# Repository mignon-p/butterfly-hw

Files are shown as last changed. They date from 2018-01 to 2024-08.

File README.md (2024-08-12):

This repository contains the [KiCad][5] and [Gerber][6] files for a
PCB nightlight shaped like a butterfly.

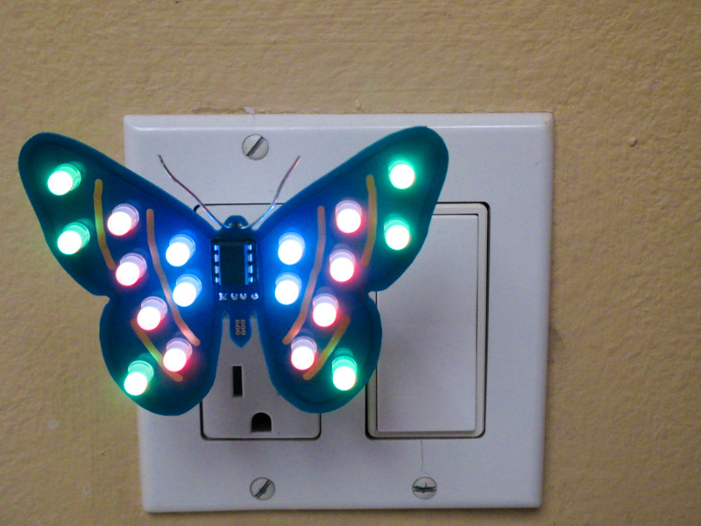
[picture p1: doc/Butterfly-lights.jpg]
photo of nightlight


The nightlight contains 18 "NeoPixel" (WS-2812) LEDs, controlled by an
ATtiny85 microcontroller.  (The firmware for the microcontroller is in
[a separate repository][7].)

There is a tiny potentiometer on the back, which can be used to
control the brightness.  (This functionality is handled in software,
so it could potentially be repurposed, such as to control speed or
color instead.)

The nightlight [plugs into a standard USB power adapter][10] (phone
charger), which handles the AC-to-DC conversion.

## Bill of Materials

* D1-D18 (qty 18) - 5mm through-hole NeoPixel.  SparkFun part
  no. [COM-12986](https://www.sparkfun.com/products/12986).  Digi-Key
  part no. [1568-1213-ND](https://www.digikey.com/product-detail/en/sparkfun-electronics/COM-12986/1568-1213-ND/5673799).
* U1 (qty 1) - ATtiny85 microcontroller.  Atmel part
  no. ATTINY85-20PU.  Digi-Key part no. [ATTINY85-20PU-ND](https://www.digikey.com/product-detail/en/microchip-technology/ATTINY85-20PU/ATTINY85-20PU-ND/735469).
* U1 (qty 1) - 8-pin DIP socket.  Assmann part no. A 08-LC-TT.
  Digi-Key part no. [AE9986-ND](https://www.digikey.com/product-detail/en/assmann-wsw-components/A-08-LC-TT/AE9986-ND/821740).
* J2 (qty 1) - USB A plug.  Molex part no. 0480370001.  Digi-Key part
  no. [WM17117-ND](https://www.digikey.com/product-detail/en/molex-llc/0480370001/WM17117-ND/857603).
* C1 (qty 1) - 0.1µF 0805 capacitor.  AVX part no. 08055C104KAT2A.
  Digi-Key part no. [478-1395-1-ND](https://www.digikey.com/product-detail/en/avx-corporation/08055C104KAT2A/478-1395-1-ND/564427).
* C2 (qty 1) - 10µF 0805 capacitor.  Kemet part no. C0805C106K8PACTU.
  Digi-Key part no. [399-4925-1-ND](https://www.digikey.com/product-detail/en/kemet/C0805C106K8PACTU/399-4925-1-ND/1090920).
* R1 (qty 1) - 470 Ohm 0805 resistor.  Rohm part no. ESR10EZPJ471.
  Digi-Key part no. [RHM470KCT-ND](https://www.digikey.com/product-detail/en/rohm-semiconductor/ESR10EZPJ471/RHM470KCT-ND/1763027).
* POT1 (qty 1) - 10k Ohm potentiometer.  Bourns part no. TC33X-2-103E.
  Digi-Key part no. [TC33X-103ECT-ND](https://www.digikey.com/product-detail/en/bourns-inc/TC33X-2-103E/TC33X-103ECT-ND/612911).
* SW1 (qty 1; optional) - Pushbutton.  Omron part no. B3S-1000.
  Digi-Key part no. [SW415-ND](https://www.digikey.com/product-detail/en/omron-electronics-inc-emc-div/B3S-1000/SW415-ND/20686).
* [Bare wire, 20 AWG](https://smile.amazon.com/gp/product/B01BDB8240/).
* [USB power adapter with USB A receptacle](https://smile.amazon.com/gp/product/B06Y2H4RJ6/).

## Tools

* Standard soldering tools.
* Tiny AVR Programmer.  SparkFun part
  no. [PGM-11801](https://www.sparkfun.com/products/11801).  Digi-Key
  part no. [1568-1079-ND](https://www.digikey.com/product-detail/en/sparkfun-electronics/PGM-11801/1568-1079-ND/5230948).
* Computer with [Arduino IDE](https://www.arduino.cc/en/Main/Software)
  installed.

## Circuit board

Most fabs should work fine, but I chose [JLCPCB][1].  I chose blue
soldermask for my first set of boards, but red or yellow might work,
as well.  I chose the [ENIG][2] finish.

If you're not making any changes to the board, all you need to do is
zip up the files in the `gerber` directory, and upload the zipfile to
JLCPCB.

Note that in the KiCad files and Gerber files, the "front" of the
board is actually the back, and vice-versa. This is because JLCPCB
adds a customer ID number to the front of the board, but I wanted the
number to be on the actual back of the board, where it doesn't disrupt
the esthetics of the nightlight.  (It turns out it's
[possible to specify the location of the customer ID][9], but I hadn't
read that when I first came up with this trick.)

## Assembly

1. Solder the surface-mount components C1, C2, R1, and POT1 onto the
back of the board.

2. Solder the USB plug onto the back of the board.  The plug is meant
to be used at a right angle, so some surgery is required.  Use
needle-nose pliers to bend the pins so that they are straight, rather
than at a right angle.  Insert the pins through the holes in the
board.  Use Scotch tape to hold the plug in place.  Trim the pins just
a little bit, so they don't protrude quite so far through the board.
Solder the pins to the board.  Remove the Scotch tape from the back.
Then, create a bead of solder all the way around where the plug
touches the board on the back, to hold it in place firmly.

3. Solder the 8-pin DIP socket to the front of the board.  The
"U"-shaped indentation should point toward the top of the butterfly.

4. Solder the 18 LEDs to the front of the board.  The LED should be
positioned so that the square pad gets one of the longer legs, not one
of the shorter ones.

5. Create the butterfly's antennae by inserting a length of bare wire
into the holes on the butterfly's head.  (These two holes are
represented by J3 on the schematic.)  It's a tight fit, so friction
may be enough to hold the wire in place, but you can always solder it
to be sure.

6. Program [the firmware][7] into the ATtiny85 chip.

7. Insert the ATtiny85 into the socket on the butterfly.  The dot on
the chip should be in the upper-left corner.

8. Plug the butterfly into the USB power adapter.

9. Plug the power adapter into the wall.

## Bonus Button

SW1 can optionally be populated with a surface-mount pushbutton, which
is connected to physical pin 5 of the ATtiny85.  (Arduino digital pin
0.)  This is not used in the default firmware, and I don't normally
populate it.  But, you can populate it if you want to have an
additional input in custom firmware that you write.  The pushbutton
pulls the pin to GND, so you'll need to activate the internal pullup.

## License

This design is licensed under the
[Creative Commons Attribution-ShareAlike 4.0 International license][12].

Some of the footprints in `myLibrary.pretty` are based on footprints
in the [KiCad library][14], which is licensed under the
[KiCad library license][15] (which is now also CC-BY-SA-4.0, with an
exception).  The footprint in `digikey-footprints.pretty` is a
modified version of a footprint from the [Digi-Key KiCad library][3],
which is licensed under [the same terms][4] as the KiCad library.

[1]: https://jlcpcb.com/quote
[2]: https://en.wikipedia.org/wiki/Electroless_nickel_immersion_gold
[3]: https://github.com/digikey/digikey-kicad-library
[4]: https://github.com/digikey/digikey-kicad-library/blob/master/LICENSE.md
[5]: http://kicad.org/
[6]: https://en.wikipedia.org/wiki/Gerber_format
[7]: https://github.com/ppelleti/butterfly-fw
[9]: https://support.jlcpcb.com/article/28-how-to-remove-the-customer-id-on-the-pcb
[10]: doc/Butterfly-adapter.jpg
[12]: https://creativecommons.org/licenses/by-sa/4.0/
[14]: https://github.com/KiCad/kicad-footprints
[15]: https://forum.kicad.info/t/kicad-library-licensing/7856

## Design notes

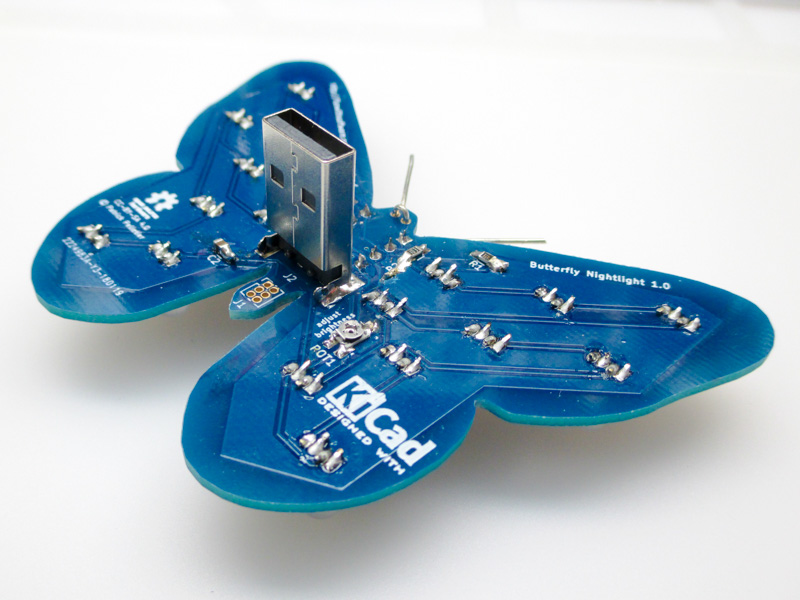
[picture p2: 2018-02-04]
doc/Butterfly-back.jpg

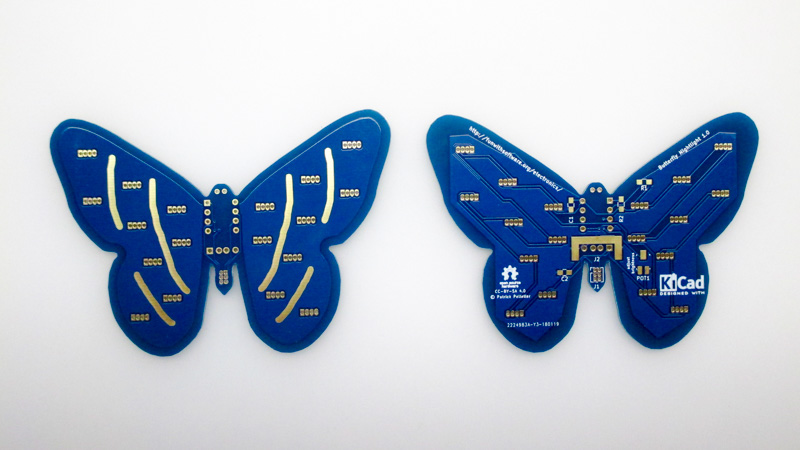
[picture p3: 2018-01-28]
doc/Butterfly-boards.jpg

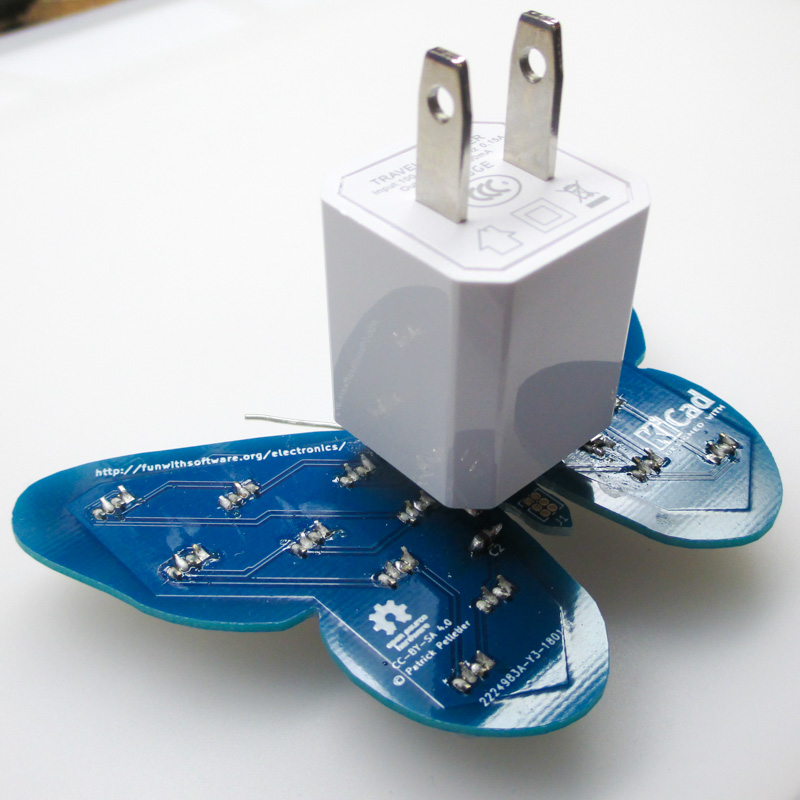
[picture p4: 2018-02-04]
doc/Butterfly-adapter.jpg

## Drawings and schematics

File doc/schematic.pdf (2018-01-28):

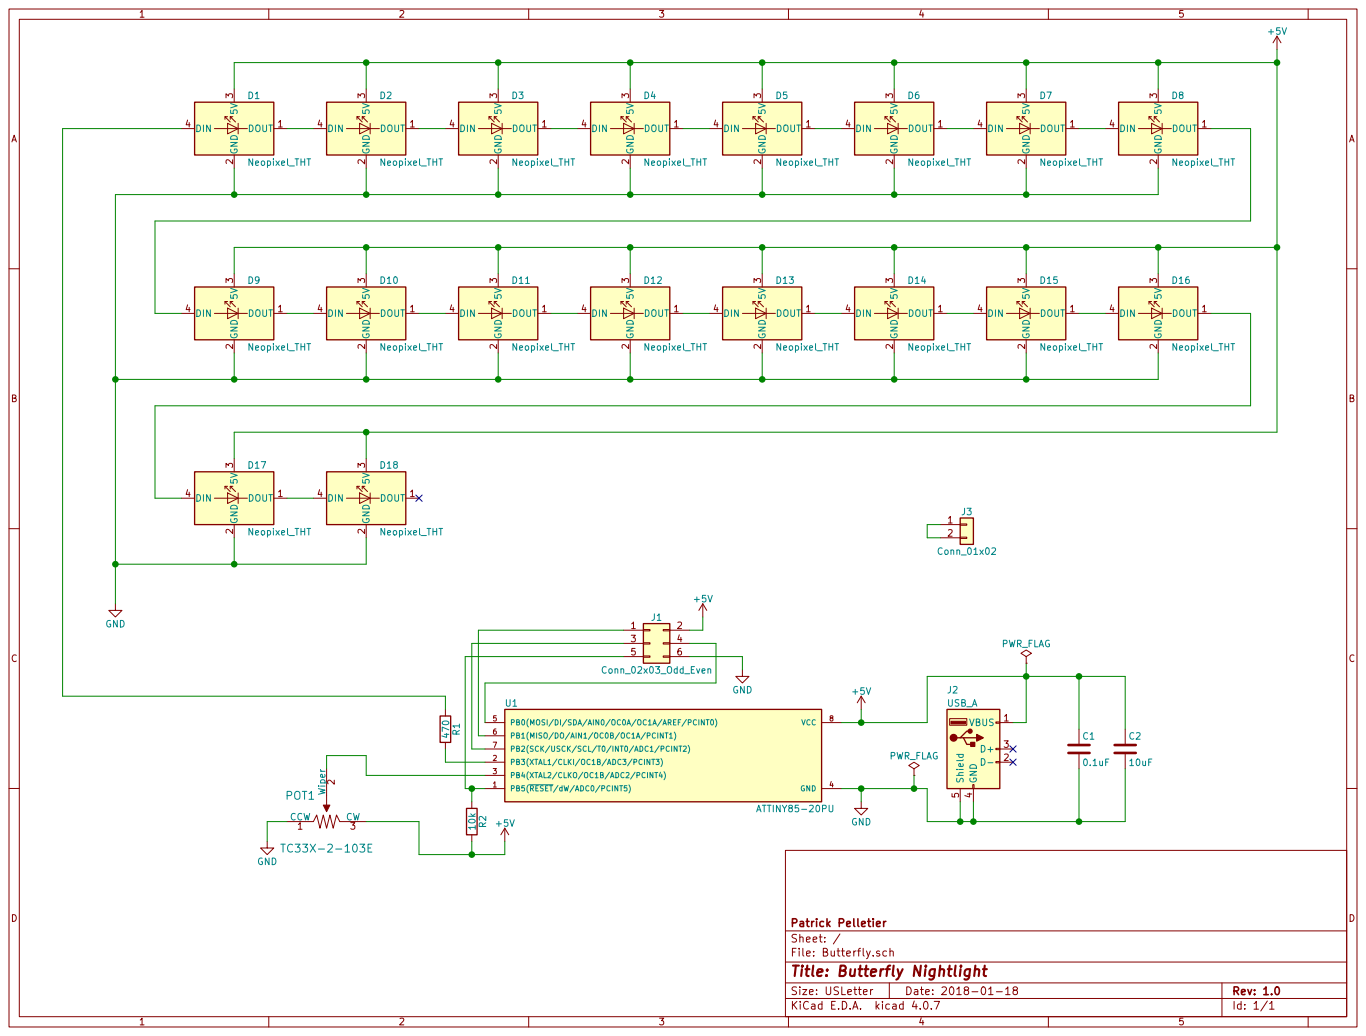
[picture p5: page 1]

Id: 1/1 Title: Butterfly Nightlight

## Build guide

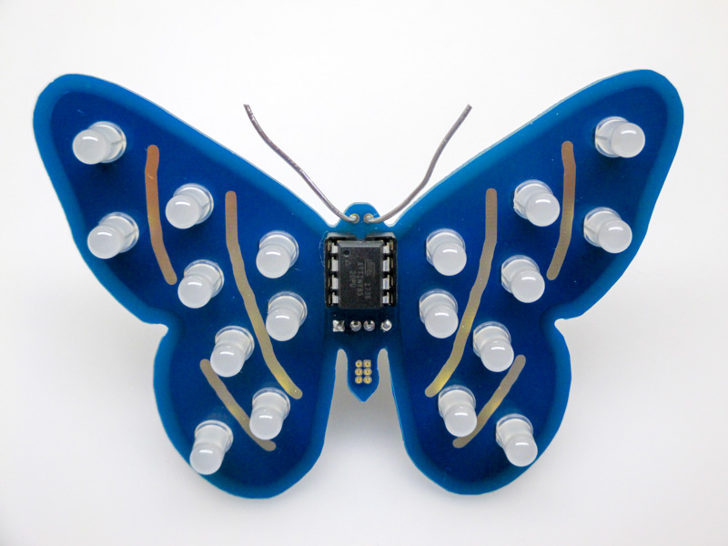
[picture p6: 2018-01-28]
doc/Butterfly-assembled.jpg

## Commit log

2018-01-14 Initial commit.
    [Butterfly.kicad_pcb, Butterfly.sch]
2018-01-16 Round off x to 145.
    [Butterfly.kicad_pcb]
2018-01-16 Dummy filled zone.
    [Butterfly.kicad_pcb]
2018-01-16 Use wing shape for filled zone.
    [Butterfly.kicad_pcb]
2018-01-16 Move zone to correct position.
    [Butterfly.kicad_pcb]
2018-01-16 Use script to mirror other half.
    [Butterfly.kicad_pcb]
2018-01-16 Re-save in KiCad to normalize file.
    [Butterfly.kicad_pcb]
2018-01-16 Change copper layer to F.Cu.
    [Butterfly.kicad_pcb]
2018-01-16 Copper decorations for left wing.
2018-01-16 Copper decorations for right wing.
2018-01-16 Instantiate left wing markings.
    [Butterfly.kicad_pcb]
2018-01-16 Copper patterns on both wings.
    [Butterfly.kicad_pcb]
2018-01-16 Getting started on schematic.
    [Butterfly.sch]
2018-01-16 Added 24 LEDs.
    [Butterfly.sch]
2018-01-16 Add 6-pin AVR ISP header.
    [Butterfly.sch]
2018-01-16 USB-A plug footprint.
2018-01-17 Added USB connector to schematic.
    [Butterfly.sch]
2018-01-17 Annotate schematic.
    [Butterfly.sch]
2018-01-17 Associate footprints.
    [Butterfly.sch]
2018-01-17 Add capacitors.
    [Butterfly.sch]
2018-01-17 Trying to position footprints; not enough room.
    [Butterfly.kicad_pcb]
2018-01-17 Moving stuff around.
    [Butterfly.kicad_pcb]
2018-01-17 Seeing how much can fit on the body.
    [Butterfly.kicad_pcb]
2018-01-17 Position LED footprints.
    [Butterfly.kicad_pcb]
2018-01-17 Remove extra LEDs.
    [Butterfly.sch]
2018-01-17 Change some footprint associations.
    [Butterfly.sch]
2018-01-17 Moved some footprints around.
    [Butterfly.kicad_pcb]
2018-01-17 Position SMT footprints.
    [Butterfly.kicad_pcb]
2018-01-17 Use front wing zones for +5V.
    [Butterfly.kicad_pcb]
2018-01-17 Add GND zone on back.
    [Butterfly.kicad_pcb]
2018-01-17 Draw traces on left wing.
    [Butterfly.kicad_pcb]
2018-01-17 Routing more tracks.
    [Butterfly.kicad_pcb]
2018-01-17 I think I got everything to fit.
    [Butterfly.kicad_pcb]
2018-01-17 Use potentiometer from Digi-Key library.
    [Butterfly.sch]
2018-01-17 Place potentiometer.
    [Butterfly.kicad_pcb]
2018-01-17 Set design rules.
    [Butterfly.kicad_pcb]
2018-01-17 Fill zones.
    [Butterfly.kicad_pcb]
2018-01-17 Add antenna holes.
    [Butterfly.kicad_pcb, Butterfly.sch]
2018-01-17 Set solder mask clearance to 0.
    [Butterfly.kicad_pcb]
2018-01-17 Center U1 exactly.
    [Butterfly.kicad_pcb]
2018-01-17 Center J1 exactly.
    [Butterfly.kicad_pcb]
2018-01-17 Clean up a few tracks.
    [Butterfly.kicad_pcb]
2018-01-17 Copy footprints from KiCad library.
2018-01-17 Remove silkscreen on local copies of footprints.
2018-01-17 Associate local versions of footprints.
    [Butterfly.sch]
2018-01-17 Propagate new footprint associations to layout.
    [Butterfly.kicad_pcb]
2018-01-17 Flip board over, so back is front.
    [Butterfly.kicad_pcb]
2018-01-17 Add text on silkscreen.
    [Butterfly.kicad_pcb]
2018-01-18 Add metadata.
    [Butterfly.kicad_pcb]
2018-01-18 Make silkscreen text bigger.
    [Butterfly.kicad_pcb]
2018-01-18 Expand GND zone.
    [Butterfly.kicad_pcb]
2018-01-18 Expand GND zone some more.
    [Butterfly.kicad_pcb]
2018-01-18 Make pads on pot bigger, for easier hand soldering.
2018-01-18 Use new pot footprint.
    [Butterfly.kicad_pcb]
2018-01-18 Generate Gerbers.
    [Butterfly-B.Cu.gbl, Butterfly-B.Mask.gbs, Butterfly-B.SilkS.gbo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]
2018-01-18 Settings for Gerber generation.
    [Butterfly.kicad_pcb]
2018-01-26 Toggle some layer visibility.
    [Butterfly.kicad_pcb]
2018-01-27 Add date and title to schematic.
    [Butterfly.sch]
2018-02-04 Add pictures of back of board.
2018-02-06 Mention USB power in the initial blurb.
2018-02-21 Try to avoid delamination of POT1 pads.
    [Butterfly.kicad_pcb]
2018-02-21 Remove ISP header; I wasn't using it.
    [Butterfly.kicad_pcb, Butterfly.sch]
2018-02-21 Bump version number up to 1.1.
    [Butterfly.kicad_pcb]
2018-02-21 Remove text under OSHW logo. It didn't come out well.
    [Butterfly.kicad_pcb]
2018-02-21 Add AbsMaxRat logo.
    [Butterfly.kicad_pcb]
2018-02-21 Added bonus button.
    [Butterfly.kicad_pcb, Butterfly.sch]
2018-02-21 Regenerate Gerbers.
    [Butterfly-B.Cu.gbl, Butterfly-B.Mask.gbs, Butterfly-B.SilkS.gbo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]
2018-03-06 Move vias to be more out of the way.
    [Butterfly.kicad_pcb]
2018-03-06 Bump version number.
    [Butterfly.kicad_pcb]
2018-03-06 Make some text bigger.
    [Butterfly.kicad_pcb]
2018-03-22 Use filled zones instead of random tracks to discourage delamination.
    [Butterfly.kicad_pcb]
2018-03-22 Reduce zone clearance from 20 mil to 12 mil.
    [Butterfly.kicad_pcb]
2019-09-20 Draw GND fill rectangle around the whole thing, instead of a weird polygon.
    [Butterfly.kicad_pcb]
2021-10-22 Link to kicad.org
    https://forum.kicad.info/t/warning-avoid-all-links-to-kicad-pcb-org-use-kicad-org/31521
